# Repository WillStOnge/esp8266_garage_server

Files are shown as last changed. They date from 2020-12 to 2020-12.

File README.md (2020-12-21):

# ESP8266 Garage Server

This is intended for use with a Homebridge server which interacts with this 'API'. My implementation can be found at [WillStOnge/homebridge-garagedoor-esp8266](https://github.com/WillStOnge/homebridge-garagedoor-esp8266)

## Configuration
There isn't too much to configure. All you need to do is enter your network SSID and password into the define statements on lines 14 and 15. If you want the relay to remain on for more/less time, this can be altered on line 11 (time is in milliseconds). Also, make sure that your relay and sensors are on the same GPIO lines as described on lines 7, 8, and 9.

## Wiring Diagram
I used an ESP8266 develoment board and some blank PCBs for ease of soldering.

This is the schematic for this setup:

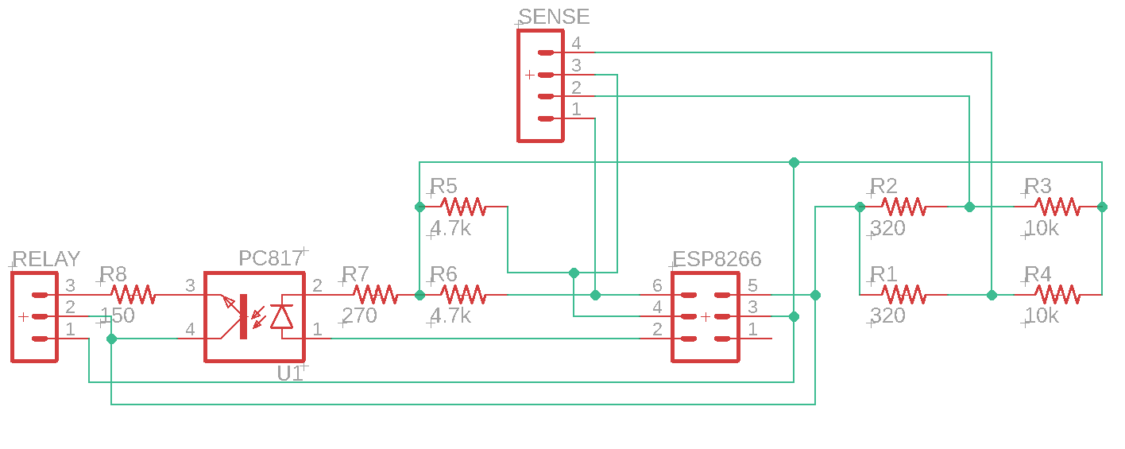
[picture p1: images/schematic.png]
Schematic


It doesn't include the ESP8266, but the GPIO lines are clearly labeled. When attaching to your garage, make sure your lines are not backwards or the door will not open/close.

This is the final PCB:

Final PCB

I decided to solder it to a blank PCB since soldering open is sketchy and messy. I then threw it in a plastic box and sealed it off to prevent bugs/dust from getting in.

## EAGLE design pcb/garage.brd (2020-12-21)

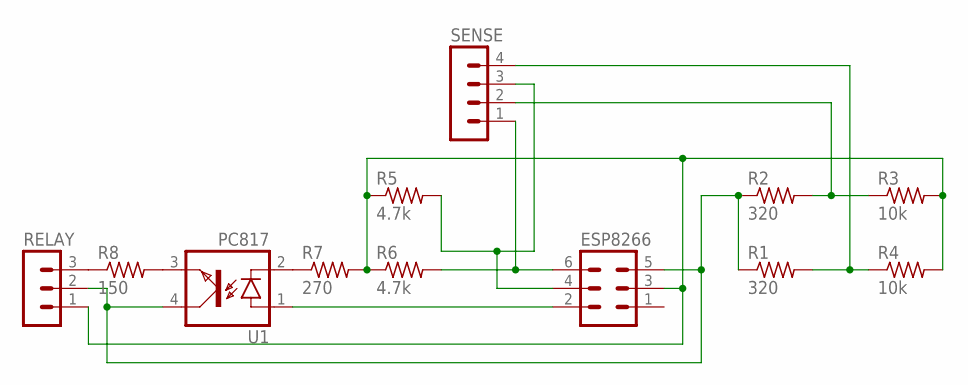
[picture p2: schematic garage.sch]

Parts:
ESP8266: MA03-2
R1, R2: 320; 0207/2V
R3, R4: 10k; 0207/2V
R5, R6: 4.7k; 0207/2V
R7: 270; 0207/2V
R8: 150; 0207/2V
RELAY: MA03-1
SENSE: MA04-1
U1: PC817; DIL04

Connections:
unnamed: ESP8266.2, U1.1 (A)
unnamed: ESP8266.6, R6.2, SENSE.1
unnamed: R8.1, RELAY.3
unnamed: R2.2, R3.1, SENSE.2
unnamed: R1.2, R4.1, SENSE.4
unnamed: ESP8266.3, R3.2, R4.2, R5.1, R6.1, R7.2, RELAY.1
unnamed: ESP8266.5, R1.1, R2.1, RELAY.2, U1.4 (COL)
unnamed: R7.1, U1.2 (C)
unnamed: ESP8266.4, R5.2, SENSE.3
unnamed: R8.2, U1.3 (EMIT)

Board: 2 copper layers, 12 parts (0 on the bottom side), 10 nets, no tracks yet.

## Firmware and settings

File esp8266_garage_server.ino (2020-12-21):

#include <ESP8266WiFi.h>
#include <WiFiClient.h>
#include <ESP8266WebServer.h>
#include <ESP8266mDNS.h>

// Pin used to hookup the relay and sensors.
#define RELAY_PIN 14
#define OPEN_SENSOR 12
#define CLOSED_SENSOR 13

#define RELAY_TIME 1000

// Place network credentials here.
#define SSID "Will_2.4G"
#define PASSWORD "horatio0522"

// CLOSED and CLOSING is already defined in ESP8266WiFi.h.
enum DoorState { OPEN, CLOSED1, OPENING, CLOSING1, STOPPED } state;

ESP8266WebServer server(80);

void setup(void)
{
  Serial.begin(115200);
  WiFi.begin(SSID, PASSWORD);

  // Waiting for connection.
  while (WiFi.status() != WL_CONNECTED)
    delay(500);

  Serial.print("\nConnected to ");
  Serial.println(SSID);

  pinMode(RELAY_PIN, OUTPUT);
  pinMode(OPEN_SENSOR, INPUT);
  pinMode(CLOSED_SENSOR, INPUT);
  digitalWrite(RELAY_PIN, LOW);

  server.on("/isopen", isOpen);
  server.on("/isclosed", isClosed);
  server.on("/trigger", trigger);

  // This is used so we can shorten '192.168.x.x' to 'garage.local'.
  if (MDNS.begin("garage"))
    Serial.println("MDNS responder started");

  server.onNotFound(notFound);
  server.begin();

  state = getState();
  Serial.printf("Door state initialized to %s.\n", stateToString());
  Serial.println("HTTP server started");
}

// Returns true if the door is open.
void isOpen()
{
  state = getState();
  
  if (state == OPEN)
    server.send(200, "application/json", "{\"state\":\"1\"}");
  else
    server.send(200, "application/json", "{\"state\":\"0\"}");

  Serial.printf("Current state: %s.\n", stateToString());
}

// Returns true if the door is closed.
void isClosed()
{
  state = getState();
  
  if (state == CLOSED1)
    server.send(200, "application/json", "{\"state\":\"1\"}");
  else
    server.send(200, "application/json", "{\"state\":\"0\"}");

  Serial.printf("Current state: %s.\n", stateToString());
}

// Trigger the garage door to activate.
void trigger()
{
  state = getState();
  
  if (state == OPEN)  
    state = CLOSED1;
  else if (state == CLOSED1)
    state = OPENING;
  else if (state != STOPPED)
    state = STOPPED;

  Serial.printf("Triggered door. State set to %s.\n", stateToString());
  server.send(200, "text/plain", "");
  
  digitalWrite(RELAY_PIN, HIGH);
  delay(RELAY_TIME);
  digitalWrite(RELAY_PIN, LOW);
}

// Reads data from sensors to determine the doors state.
DoorState getState()
{
  int isOpen = digitalRead(OPEN_SENSOR);
  int isClosed = digitalRead(CLOSED_SENSOR);

  Serial.printf("isOpen: %d\nisClosed: %d\n", isOpen, isClosed);

  if (!isOpen && !isClosed)
    return state; // If door is neither open or closed, return the current state (CLOSING1, OPENING, or STOPPED)
  return (DoorState)!isOpen;
}

char* stateToString()
{
  switch (state)
  {
  case OPEN:
    return "OPEN";
  case CLOSED1:
    return "CLOSED";
  case STOPPED:
    return "STOPPED";
  case CLOSING1:
    return "CLOSING";
  case OPENING:
    return "OPENING";
  default:
    return "UNKNOWN";
  }
}

void loop(void)
{
  server.handleClient();
}

void notFound()
{
  server.send(404, "application/json", "{\"message\":\"Page not found\"}");
}

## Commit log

2020-12-07 Added schematic to README
2020-12-07 Added Arduino code
2020-12-21 Added eagle files
    [garage.brd, garage.sch]
